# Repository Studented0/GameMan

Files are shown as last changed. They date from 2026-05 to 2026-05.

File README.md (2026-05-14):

# GameMan

A handheld Game Boy emulator with a Fat form factor,  tactile buttons, 3.5" display, and USB-C for both charging and loading ROMs. Built around the ESP32-S3.

## Schematic

GameMan

## PCB



Full schematic PDF: [GameMan.pdf](https://github.com/user-attachments/files/27543807/GameMan.pdf) 

## How it works

The ESP32-S3 runs Peanut-GB and drives a 3.5" SPI display. ROMs live on an SD card built into the display module. , drag a ROM onto it, unplug, and play. 

Battery charging goes through a TP4056. The ESP32 controls the charge enable pin in software so I can add things like charge limiting later. Battery voltage reads through a voltage divider on an ADC pin for a charge percentage estimate.

Controls are nine buttons total. The D-pad is a 5-button cluster with SELECT in the center. A, B, Start, and Menu sit on the right side.

## Specs

| Component | Part |
|---|---|
| MCU | ESP32-S3-DevKitC-1 N8R8 |
| Display | 3.5" IPS ST7796U, 480×320 |
| Touch | FT6336U over I2C |
| Storage | Micro SD (on display module) |
| Battery | 3.7V LiPo |
| Charging | TP4056 |
| Regulation | AMS1117-3.3 LDO |
| USB | USB-C, charging + OTG game loading |

Full BOM is in `/Production/bom.csv`.

## Repo structure

- `/KiCad` — schematic and PCB files
- `/Production` — gerbers, BOM, drill files
- `/Firmware` — in progress

## Status

PCB design done. Firmware not started yet

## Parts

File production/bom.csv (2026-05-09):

Designator | Footprint | Quantity | Value | LCSC Part #
BT1 | JST_PH_B2B-PH-K_1x02_P2.00mm_Vertical | 1 | Battery_Cell
C1, C2, C3, C4, C8 | 0402 | 5 | 100nF
C5, C6, C7 | 0805 | 3 | 10µF
D1 | 0402 | 1 | LEDGREEN
D2 | 0402 | 1 | LEDRED
J1 | USB_C_Receptacle_HRO_TYPE-C-31-M-12 | 1 | USB_C_Receptacle_USB2.0_16P
JDISPLAY1 | PinHeader_1x14_P2.54mm_Vertical | 1 | Conn_01x14
LS1 | PinHeader_1x02_P2.54mm_Vertical | 1 | Speaker
Q1 | SOT-23 | 1 | S8050
R1, R2 | 0402 | 2 | 1k
R10, R9 | 0402 | 2 | 100k
R3, R4 | 0402 | 2 | 5.1k
R5 | 0402 | 1 | 2.4k
R6, R8 | 0402 | 2 | 10k
R7 | 0402 | 1 | 100R
SW1, SW10, SW11, SW12, SW2, SW4, SW5, SW6, SW7, SW8, SW9 | SW-SMD_4P-L5.1-W5.1-P3.70-LS6.5-TL_H1.5 | 11 | TS-1187A-B-A-B | C318884
SW3 | SW_SPDT_Shouhan_MSK12C02 | 1 | SW_SPST
U1 | XCVR_ESP32-S3-DEVKITC-1-N8R2 | 1 | ESP32-S3-DEVKITC-1-N8R2
U2 | SOIC-8-1EP_3.9x4.9mm_P1.27mm_EP2.41x3.3mm_ThermalVias | 1 | TP4056-42-ESOP8
U3 | SOT-223-3_TabPin2 | 1 | AMS1117-3.3

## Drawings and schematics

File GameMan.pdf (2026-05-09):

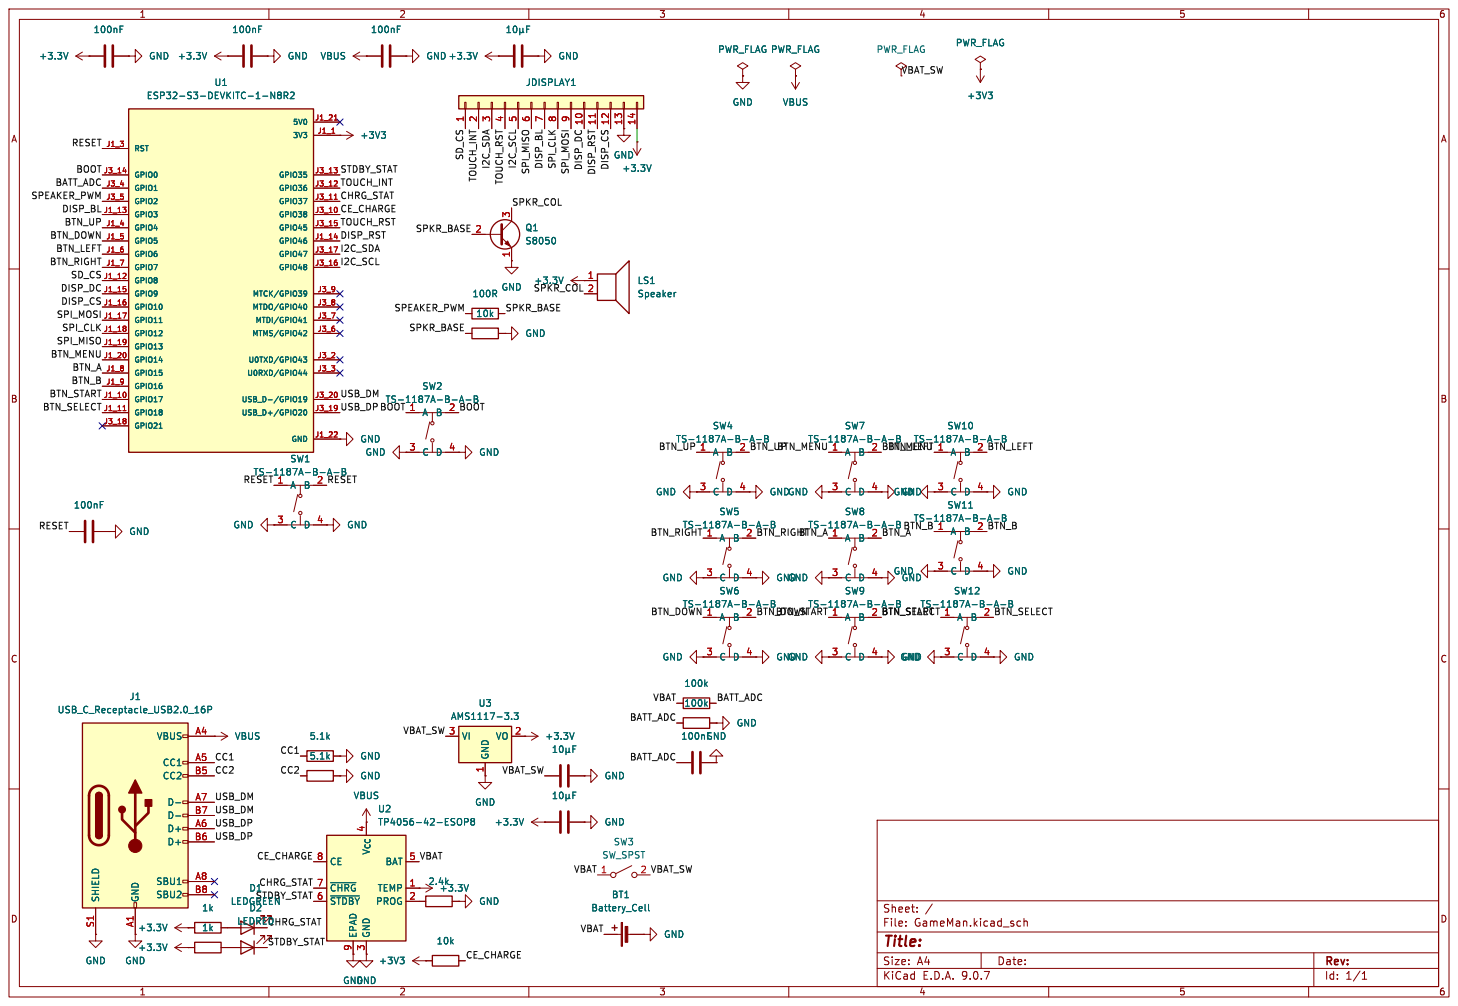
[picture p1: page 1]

Id: 1/1 Title: File: GameMan.kicad_sch Sheet: /

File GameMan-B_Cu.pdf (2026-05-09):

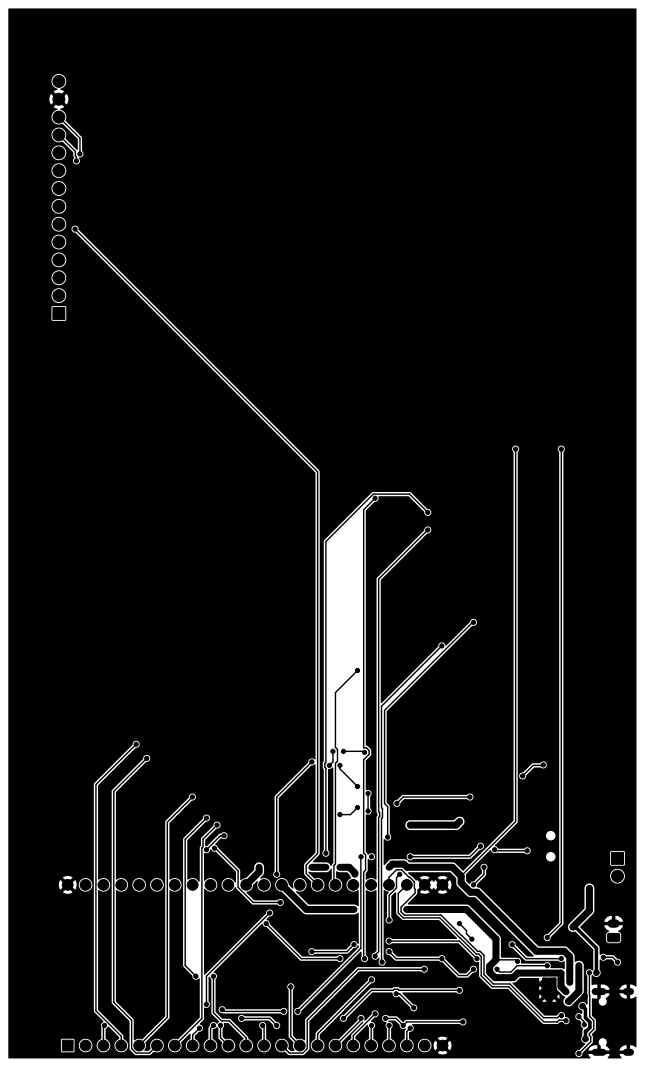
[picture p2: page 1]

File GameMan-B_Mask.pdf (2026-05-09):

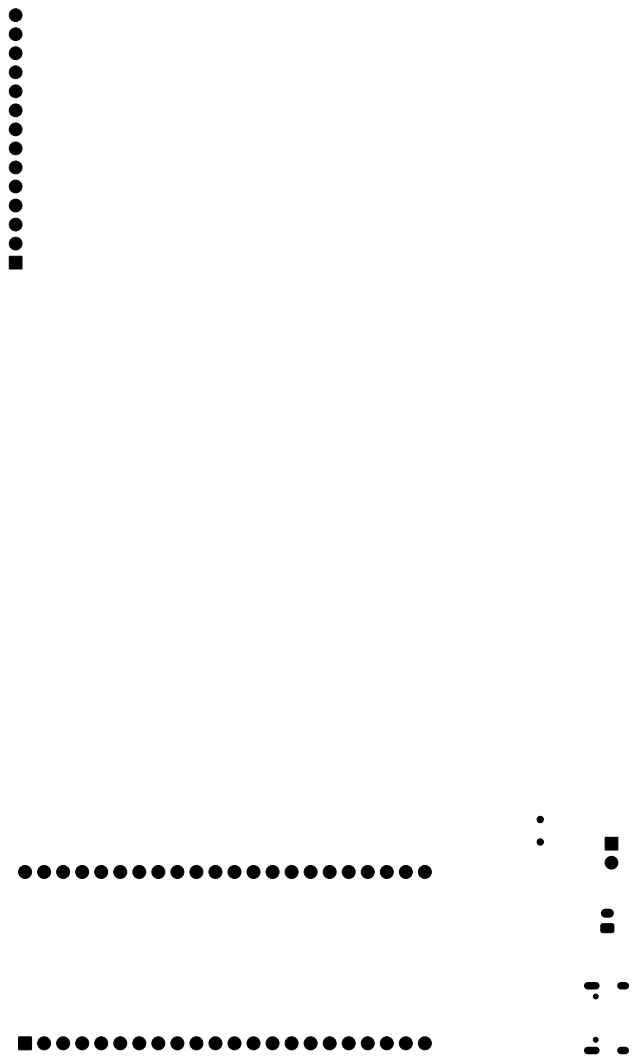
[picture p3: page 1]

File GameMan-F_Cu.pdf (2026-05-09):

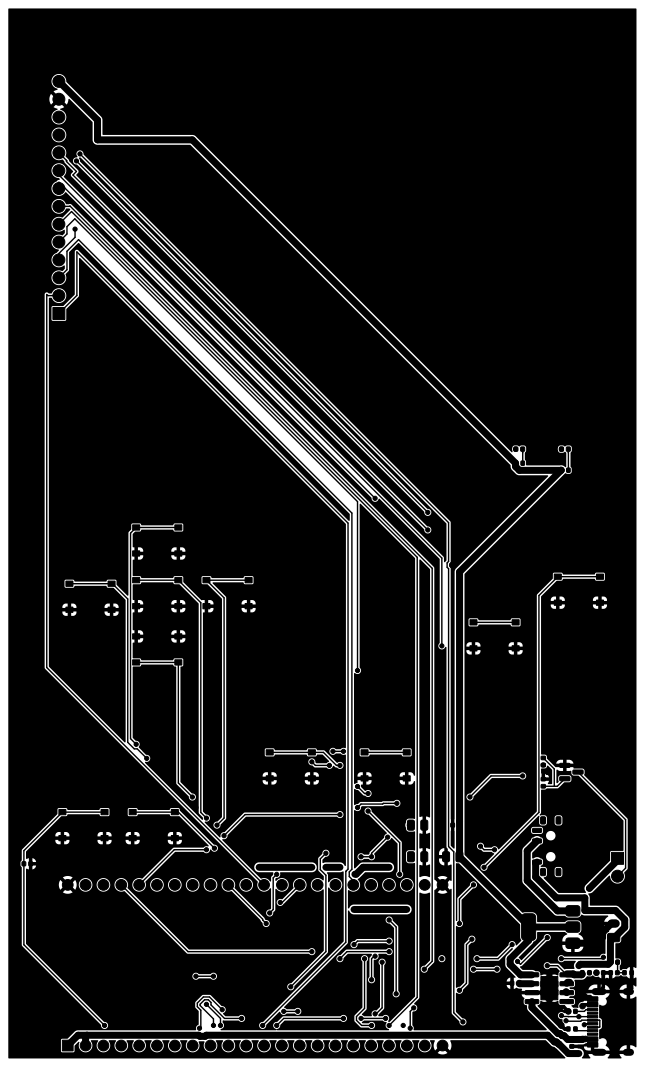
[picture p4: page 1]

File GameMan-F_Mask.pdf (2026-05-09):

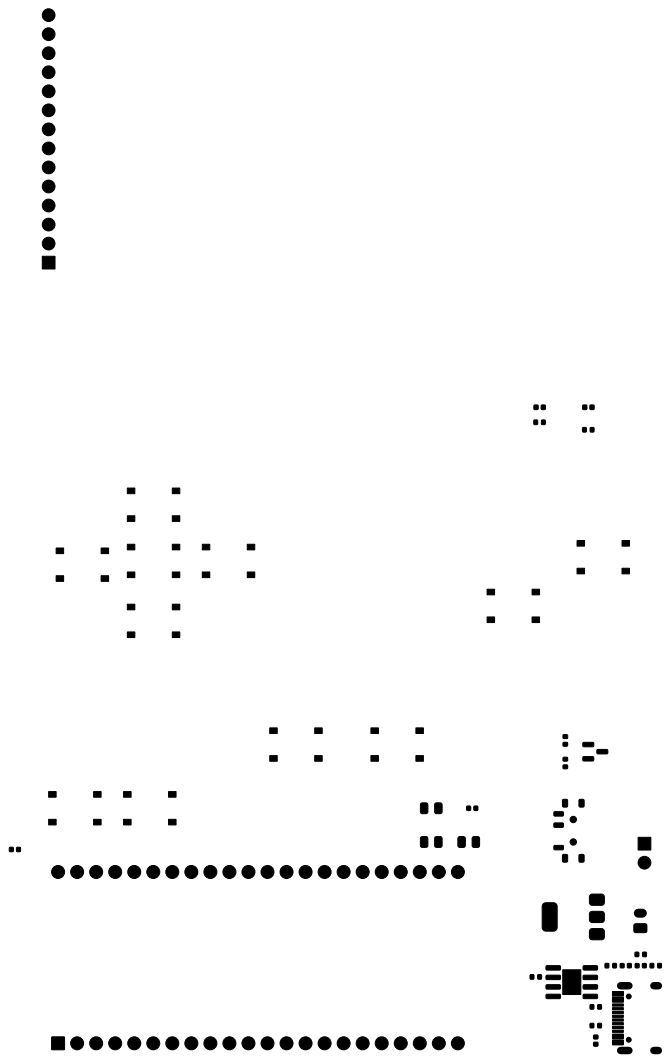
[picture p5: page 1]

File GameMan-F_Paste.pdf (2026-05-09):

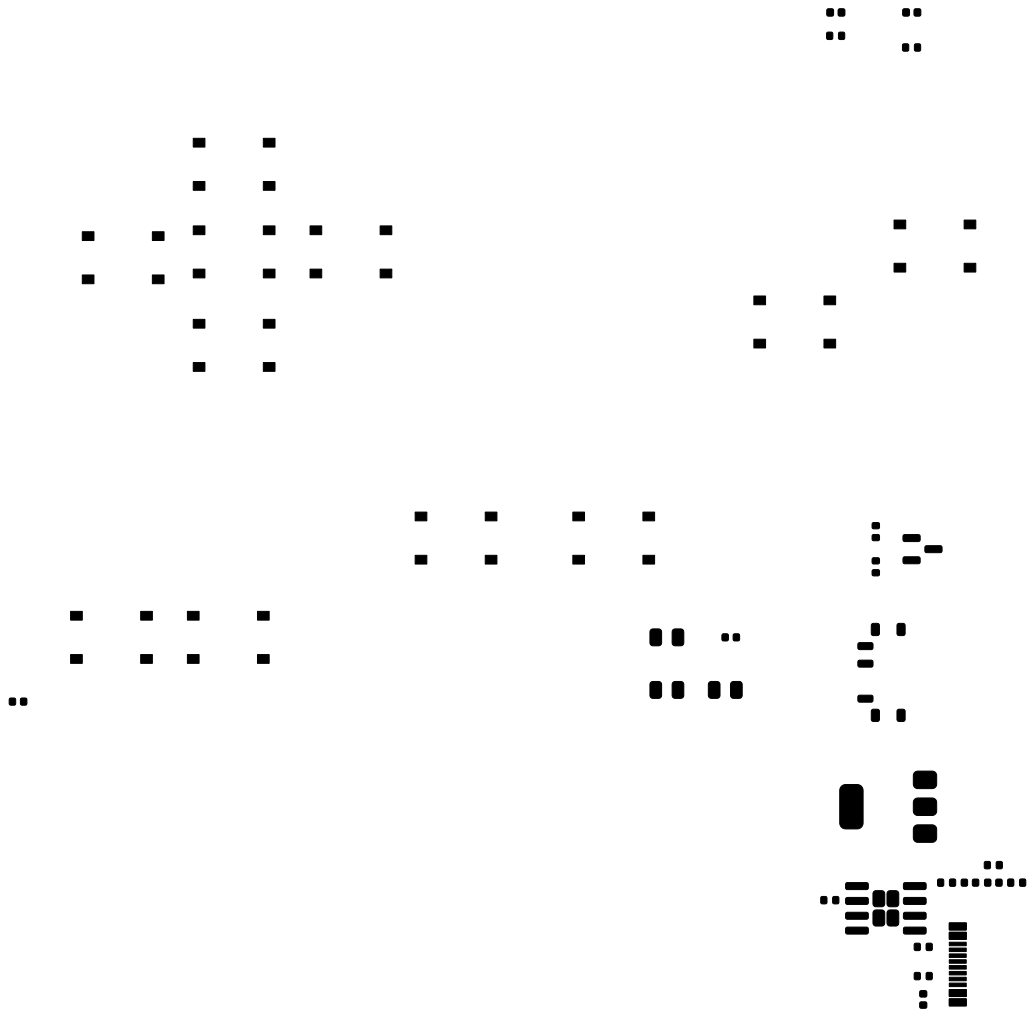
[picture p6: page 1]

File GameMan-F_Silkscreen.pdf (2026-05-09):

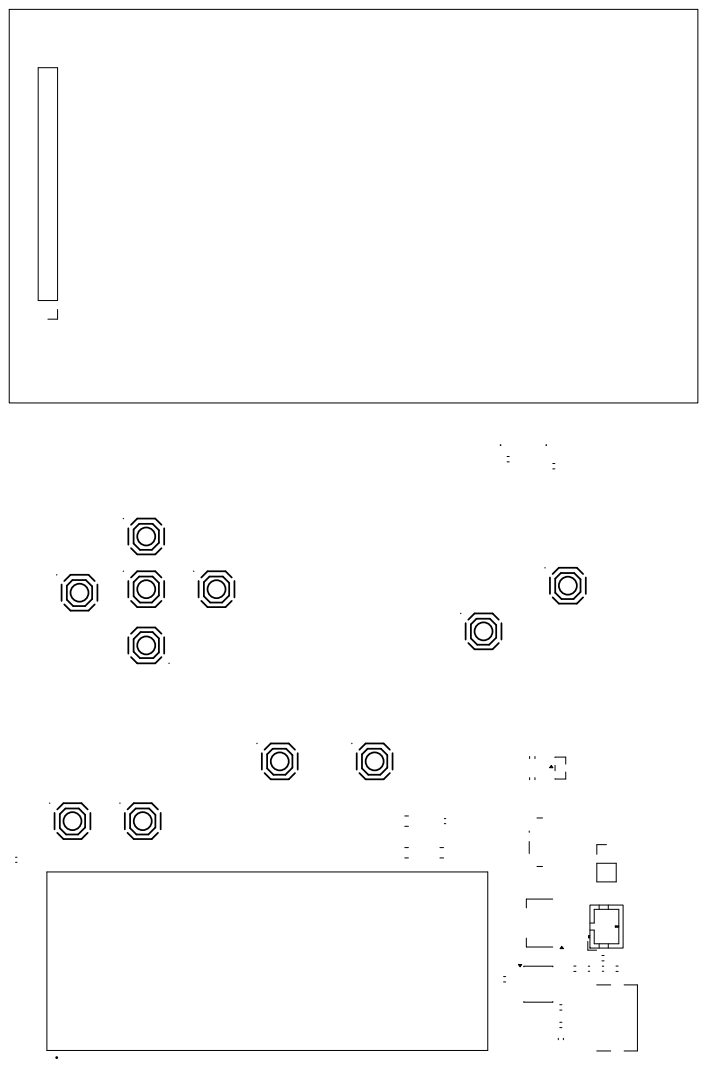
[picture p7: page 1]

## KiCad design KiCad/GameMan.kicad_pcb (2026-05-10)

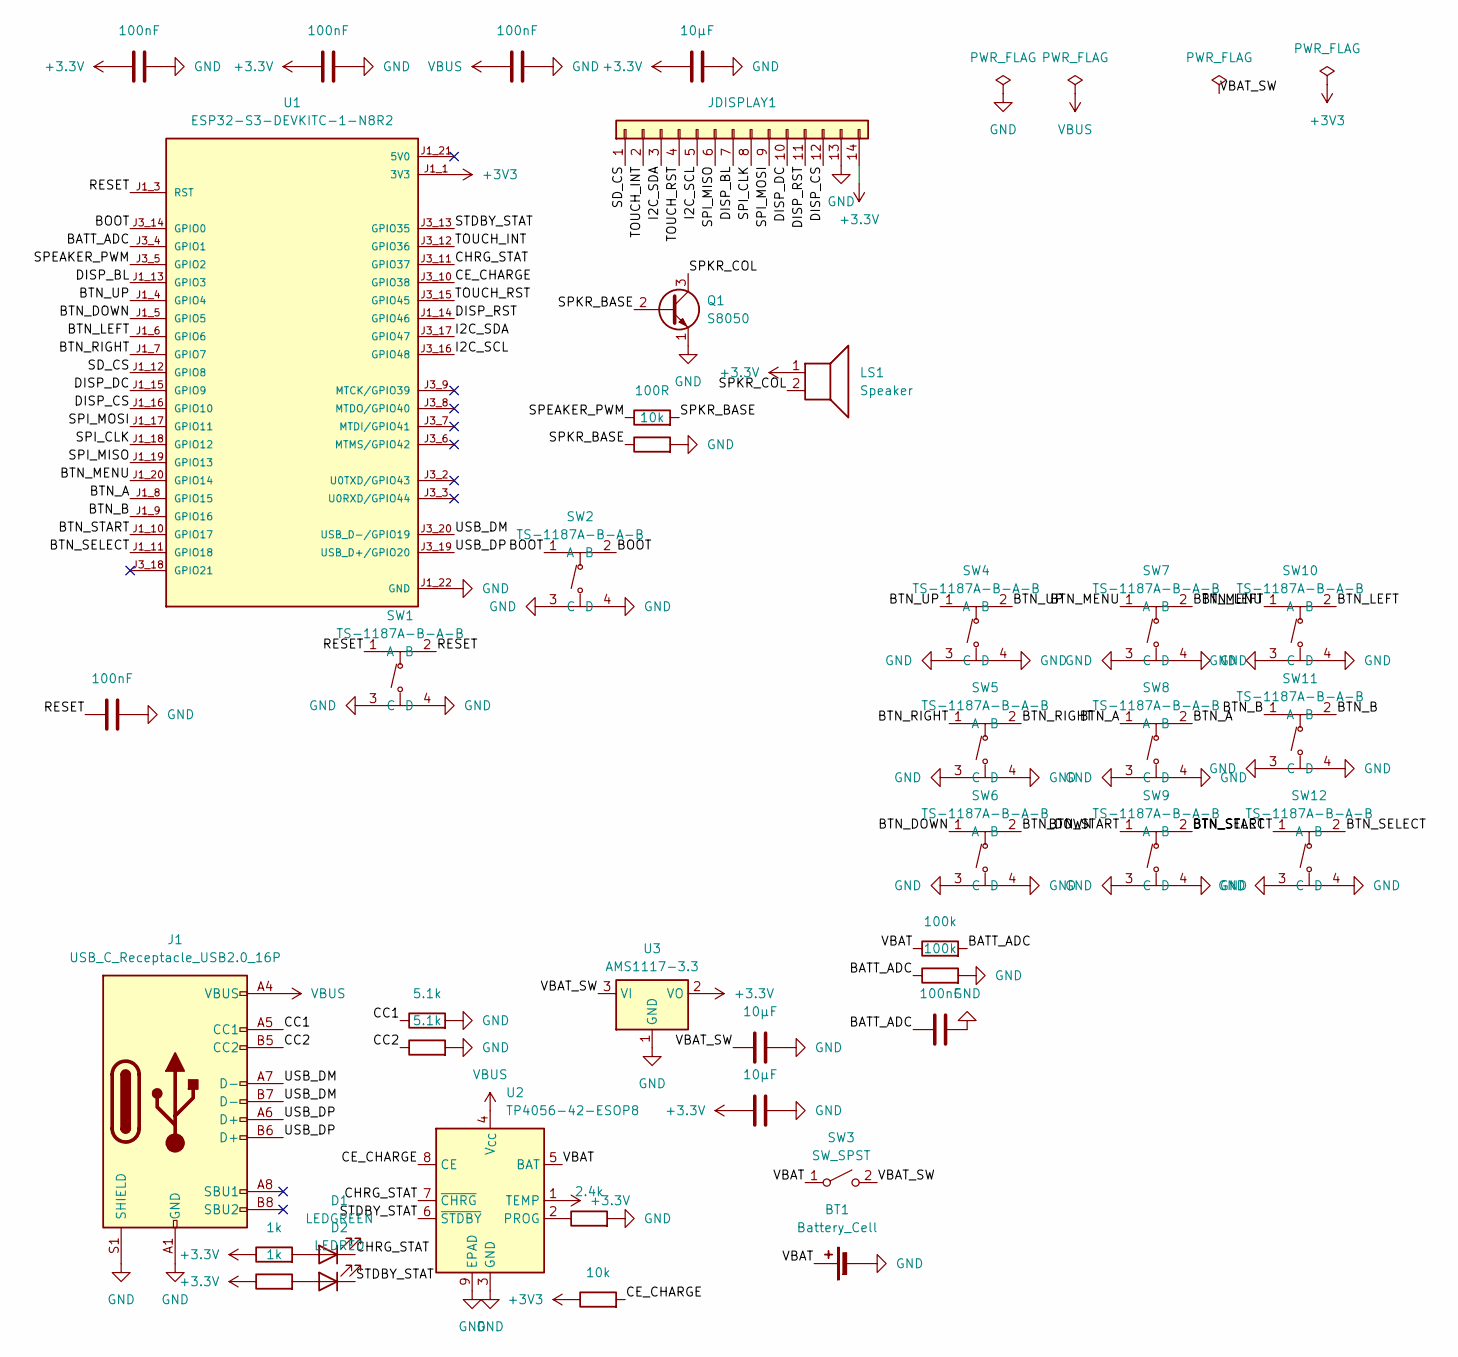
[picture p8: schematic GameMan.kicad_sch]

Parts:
BT1: Battery_Cell; JST_PH_B2B-PH-K_1x02_P2.00mm_Vertical
C1, C2, C3, C4, C8: 100nF; C_0402_1005Metric
C5, C6, C7: 10µF; C_0805_2012Metric
D1: LEDGREEN; LED_0402_1005Metric
D2: LEDRED; LED_0402_1005Metric
J1: USB_C_Receptacle_USB2.0_16P; USB_C_Receptacle_HRO_TYPE-C-31-M-12
JDISPLAY1: Conn_01x14; PinHeader_1x14_P2.54mm_Vertical
LS1: Speaker; PinHeader_1x02_P2.54mm_Vertical
Q1: S8050; SOT-23
R1, R2: 1k; R_0402_1005Metric
R3, R4: 5.1k; R_0402_1005Metric
R5: 2.4k; R_0402_1005Metric
R6, R8: 10k; R_0402_1005Metric
R7: 100R; R_0402_1005Metric
R9, R10: 100k; R_0402_1005Metric
SW1, SW2, SW4, SW5, SW6, SW7, SW8, SW9, SW10, SW11, SW12: TS-1187A-B-A-B; SW-SMD_4P-L5.1-W5.1-P3.70-LS6.5-TL_H1.5; MPN TS-1187A-B-A-B; LCSC Part C318884
SW3: SW_SPST; SW_SPDT_Shouhan_MSK12C02
U1: ESP32-S3-DEVKITC-1-N8R2; XCVR_ESP32-S3-DEVKITC-1-N8R2; PARTREV V1
U2: TP4056-42-ESOP8; SOIC-8-1EP_3.9x4.9mm_P1.27mm_EP2.41x3.3mm_ThermalVias
U3: AMS1117-3.3; SOT-223-3_TabPin2

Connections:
+3.3V: C2.1, C3.1, C5.1, C7.1, JDISPLAY1.14, LS1.1, R1.1, R2.1, U2.1 (TEMP), U3.2 (VO)
+3V3: R6.1, U1.J1_1 (3V3), U1.J1_2 (3V3)
/BATT_ADC: C8.1, R9.2, R10.1, U1.J3_4 (GPIO1)
/BOOT: SW2.1 (A), SW2.2 (B), U1.J3_14 (GPIO0)
/BTN_A: SW8.1 (A), SW8.2 (B), U1.J1_8 (GPIO15)
/BTN_B: SW11.1 (A), SW11.2 (B), U1.J1_9 (GPIO16)
/BTN_DOWN: SW6.1 (A), SW6.2 (B), U1.J1_5 (GPIO5)
/BTN_LEFT: SW10.1 (A), SW10.2 (B), U1.J1_6 (GPIO6)
/BTN_MENU: SW7.1 (A), SW7.2 (B), U1.J1_20 (GPIO14)
/BTN_RIGHT: SW5.1 (A), SW5.2 (B), U1.J1_7 (GPIO7)
/BTN_SELECT: SW12.1 (A), SW12.2 (B), U1.J1_11 (GPIO18)
/BTN_START: SW9.1 (A), SW9.2 (B), U1.J1_10 (GPIO17)
/BTN_UP: SW4.1 (A), SW4.2 (B), U1.J1_4 (GPIO4)
/CC1: J1.A5 (CC1), R3.1
/CC2: J1.B5 (CC2), R4.1
/CE_CHARGE: R6.2, U1.J3_10 (GPIO38), U2.8 (CE)
/CHRG_STAT: D1.1 (K), U1.J3_11 (GPIO37), U2.7 (~CHRG)
/DISP_BL: JDISPLAY1.7, U1.J1_13 (GPIO3)
/DISP_CS: JDISPLAY1.12, U1.J1_16 (GPIO10)
/DISP_DC: JDISPLAY1.10, U1.J1_15 (GPIO9)
/DISP_RST: JDISPLAY1.11, U1.J1_14 (GPIO46)
/I2C_SCL: JDISPLAY1.5, U1.J3_16 (GPIO48)
/I2C_SDA: JDISPLAY1.3, U1.J3_17 (GPIO47)
/RESET: C1.1, SW1.1 (A), SW1.2 (B), U1.J1_3 (RST)
/SD_CS: JDISPLAY1.1, U1.J1_12 (GPIO8)
/SPEAKER_PWM: R7.1, U1.J3_5 (GPIO2)
/SPI_CLK: JDISPLAY1.8, U1.J1_18 (GPIO12)
/SPI_MISO: JDISPLAY1.6, U1.J1_19 (GPIO13)
/SPI_MOSI: JDISPLAY1.9, U1.J1_17 (GPIO11)
/SPKR_BASE: Q1.2 (B), R7.2, R8.1
/SPKR_COL: LS1.2, Q1.3 (C)
/STDBY_STAT: D2.1 (K), U1.J3_13 (GPIO35), U2.6 (~STDBY)
/TOUCH_INT: JDISPLAY1.2, U1.J3_12 (GPIO36)
/TOUCH_RST: JDISPLAY1.4, U1.J3_15 (GPIO45)
/USB_DM: J1.A7 (D-), J1.B7 (D-), U1.J3_20 (USB_D-/GPIO19)
/USB_DP: J1.A6 (D+), J1.B6 (D+), U1.J3_19 (USB_D+/GPIO20)
/VBAT: BT1.1 (+), R9.1, SW3.1 (A), U2.5 (BAT)
/VBAT_SW: C6.1, SW3.2 (B), U3.3 (VI)
GND: BT1.2 (-), C1.2, C2.2, C3.2, C4.2, C5.2, C6.2, C7.2, C8.2, J1.A1 (GND), J1.A12 (GND), J1.B1 (GND), J1.B12 (GND), J1.S1 (SHIELD), JDISPLAY1.13, Q1.1 (E), R3.2, R4.2, R5.2, R8.2, R10.2, SW1.3 (C), SW1.4 (D), SW2.3 (C), SW2.4 (D), SW4.3 (C), SW4.4 (D), SW5.3 (C), SW5.4 (D), SW6.3 (C), SW6.4 (D), SW7.3 (C), SW7.4 (D), SW8.3 (C), SW8.4 (D), SW9.3 (C), SW9.4 (D), SW10.3 (C), SW10.4 (D), SW11.3 (C), SW11.4 (D), SW12.3 (C), SW12.4 (D), U1.J1_22 (GND), U1.J3_1 (GND), U1.J3_21 (GND), U1.J3_22 (GND), U2.3 (GND), U2.9 (EPAD), U3.1 (GND)
unnamed: D1.2 (A), R1.2
unnamed: D2.2 (A), R2.2
unnamed: R5.1, U2.2 (PROG)
VBUS: C4.1, J1.A4 (VBUS), J1.A9 (VBUS), J1.B4 (VBUS), J1.B9 (VBUS), U2.4 (V_{CC})

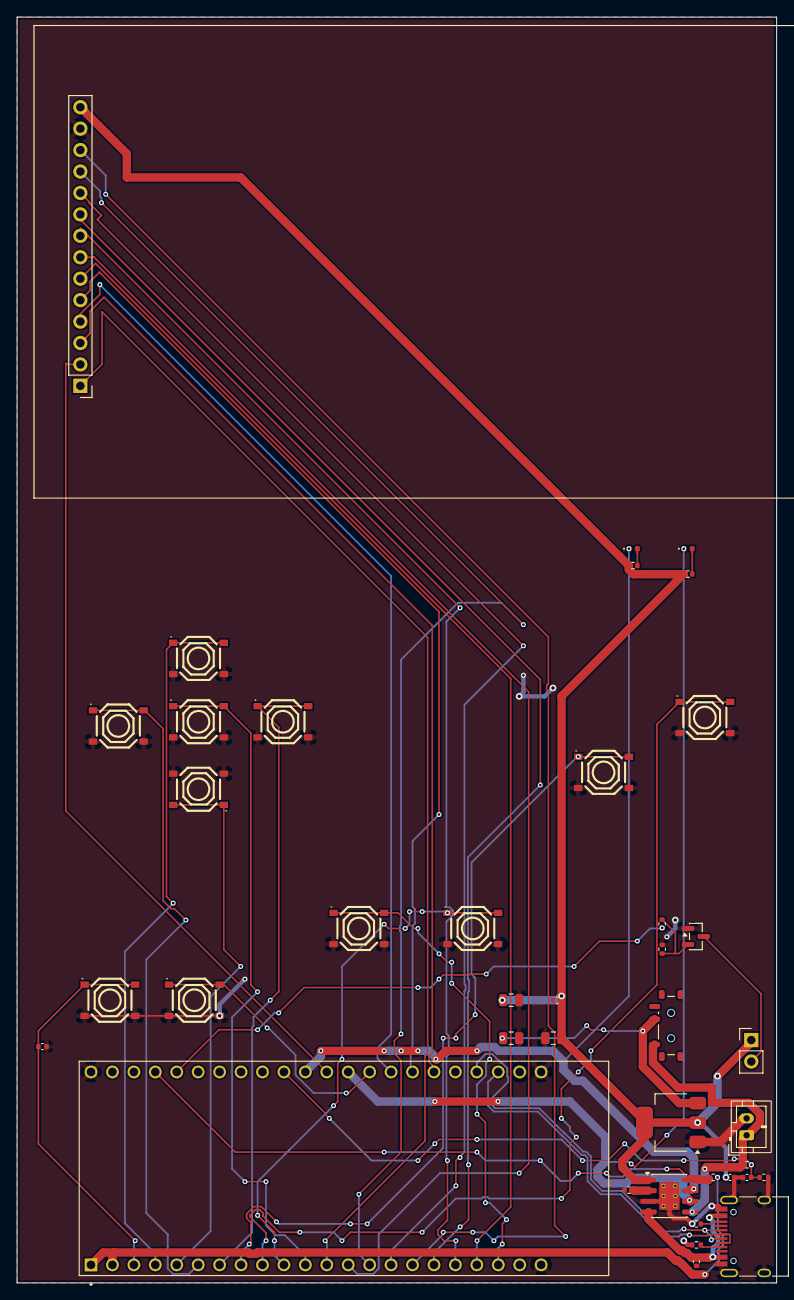
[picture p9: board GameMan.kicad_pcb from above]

Board: 2 copper layers, 90.0 x 150.0 mm, 40 parts (0 on the bottom side), 43 nets.

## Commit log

2026-05-09 PCB layout complete
    [GameMan.kicad_pcb, GameMan.kicad_sch]
2026-05-10 Polish README and reorganize folders
    [GameMan.kicad_pcb, GameMan.kicad_sch]
2026-05-10 Update README with additional schematic image
    Added an image to the schematic section and updated the text.
